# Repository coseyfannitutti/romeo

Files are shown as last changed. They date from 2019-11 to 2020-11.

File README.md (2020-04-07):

# ROMEO
 Staggered 40% QMK and VIA compatible keyboard pcb assembled with only through hole components, including USB Type-C

**[BOM, Build Guide, and Flashing Information](./doc)**

**Kits available at [cftkb.com](https://www.cftkb.com)**

**[Optional High Profile Lasercut Acrylic Case](./case)**

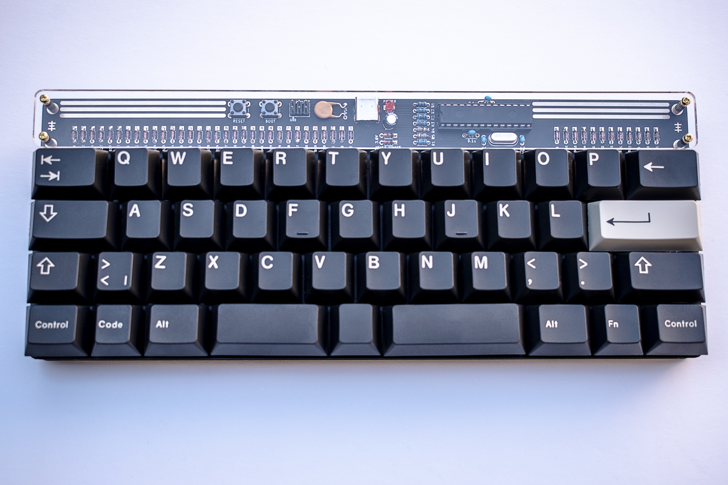
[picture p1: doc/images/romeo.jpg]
romeo

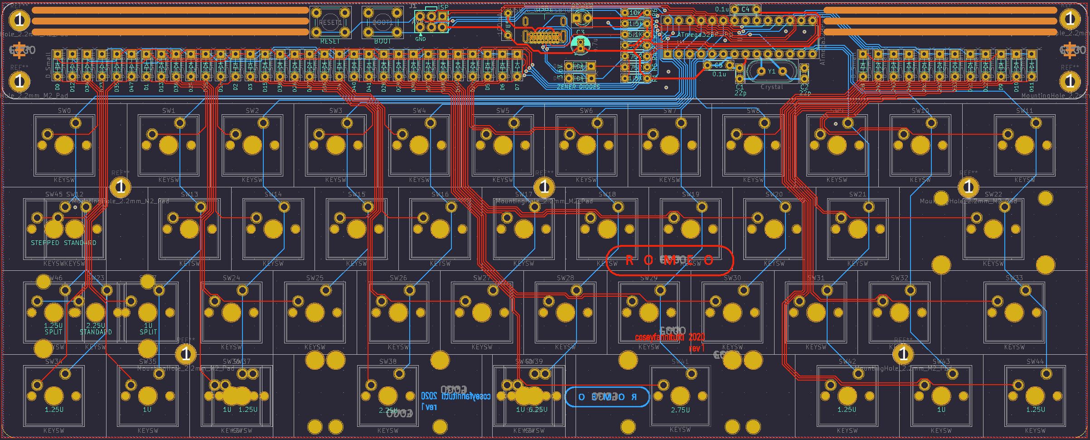
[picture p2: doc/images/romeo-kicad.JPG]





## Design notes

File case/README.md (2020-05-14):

# Lasercut Acrylic Case with POM Plate

***This is case is OPTIONAL and not required. The kit has everything you need for a fully functional keyboard.
This case uses a different plate and is NOT compatible with the plate included in the kit.
If you have already soldered switches, you will need to desolder them and swap the plate.***

***I recommend using [Ponoko](https://www.ponoko.com) to cut the pieces. They have all of the correct/required thicknesses and materials in stock and have the best pricing that I have found for multiple one-off parts. Use clear acrylic for the full range of thickness options and Delrin (POM) for the plate. For proper fit please ensure you use the correct dimensions and material thicknesses noted below. romeo-top-1.dxf must be clear for component window. 3mm pieces will have full range of color options. 4.5mm open layer will have limited color choices but will only be visible from the side.***

***Ponoko's automatic size detection when uploading is not flawless, so be sure to manually enter the dimensions below.***

## Part Dimensions/Thickness (Top to Bottom)
1. romeo-top-1.dxf - 263.7 x 115.2 mm - ***2mm thickness clear acrylic***
2. romeo-top-2.dxf ***x2 needed*** - 263.7 x 115.2 mm - ***3mm thickness acrylic (Matte/frosted or color recomended for winkeyless version to hide plate hole.)***
3. romeo-plate.dxf - 263.7 x 115.2 mm - ***1.5mm thickness DELRIN(POM)*** Can be black or white.
4. romeo-open-layer.dxf - 263.7 x 115.2 mm - ***4.5mm thickness acrylic***
5. romeo-closed-layer.dxf - 263.7 x 115.2 mm - ***3mm thickness acrylic***
6. romeo-bottom.dxf - 263.7 x 115.2 mm - ***3mm thickness acrylic***
7. romeo-foot-1.dxf - 241.1 x 22mm - ***3mm thickness acrylic***
8. romeo-foot-2.dxf - 238.1 x 19mm - ***3mm thickness acrylic***
9. romeo-foot-3.dxf - 235.1 x 16mm - ***3mm thickness acrylic***

## Screws and Standoffs
1. [22x m2x5mm screws](https://www.aliexpress.com/item/32870342767.html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,searchweb201602_7,searchweb201603_53)
2. [8x m2x14mm standoffs](https://www.aliexpress.com/item/32968906213.html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,searchweb201602_7,searchweb201603_53)
3. [3x m2x5mm standoffs](https://www.aliexpress.com/item/32968906213.html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,searchweb201602_7,searchweb201603_53)

romeo


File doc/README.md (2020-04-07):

# ROMEO

**[Build Guide](https://static1.squarespace.com/static/5c533d33348cd92b886e544d/t/5e767acd0ff82c232030b20b/1584822992123/ROMEO+BUILD+GUIDE.pdf)**

**[VIA Configurator Guide](https://static1.squarespace.com/static/5c533d33348cd92b886e544d/t/5e8bd35323fb224b2f3c259d/1586221908208/ROMEO+VIA+GUIDE.pdf)**

**[QMK Toolbox Flashing Guide (Recommended)](https://static1.squarespace.com/static/5c533d33348cd92b886e544d/t/5e73f6b325afdb570c7bbe6a/1584658100264/ROMEO+FLASHING+GUIDE.pdf)**

**[Command Line Flashing Guide (Advanced)](https://static1.squarespace.com/static/5c533d33348cd92b886e544d/t/5e73f6c5d50dac3992a99da3/1584658118097/ROMEO+FLASHING+GUIDE+-+COMMAND+LINE.pdf)**

**[Bootloader](./bootloader)**

**[BOM (Parts List)](https://octopart.com/bom-tool/7JrzAlX8)**

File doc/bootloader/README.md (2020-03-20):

# Bootloader

## If you buy a kit from cftkb.com your microcontroller already has the bootloader flashed and you do not need this.

This project uses USBaspLoader as the usb bootloader on the atmega328p.
- My custom bootloader:   
https://github.com/coseyfannitutti/USBaspLoader/tree/atmega328p
  - Please ensure you are in the atmega328p branch of my fork of the USBaspLoader repository when downloading.
  - Follow the directions in the readme for directions on setting up the build environment for your operating system as well as flash instructions.
  - Makefile.inc sets flashing device as usbtiny, as I use a sparkfun pocket avr programmer. If you need to use another programmer please edit line 41 of Makefile.inc accordingly. Only edit Makefile.inc, and NEVER directly edit the actual Makefile.
  - Commands for flashing once build environment is set up:
  
	```make flash``` (flashes makefile)
  
  	```make fuse``` (sets fuses for microcontroller)
  
## Enter bootloader mode
1. Press and hold ```BOOT``` switch
2. Tap ```RESET``` switch
3. Release ```BOOT``` switch

Alternatively, you can hold ```BOOT``` switch while inserting the USB cable.

If you have successfully entered bootloader mode you should see USBaspLoader in device manager or as a connected device in QMK Toolbox.

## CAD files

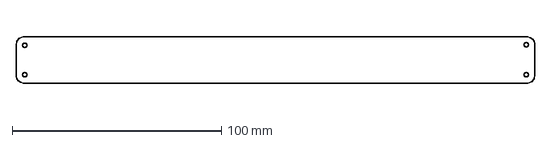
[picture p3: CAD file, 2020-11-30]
acrylic-guard.dxf
247.7 x 22.0 mm

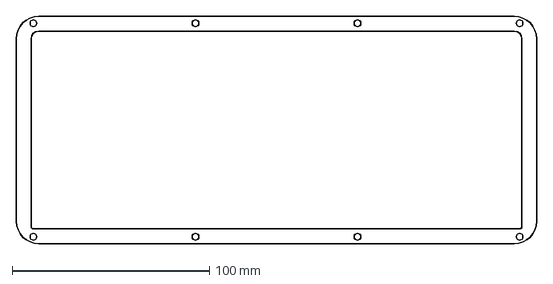
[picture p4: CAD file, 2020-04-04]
case/standard/romeo-top-2.dxf
263.7 x 115.2 mm

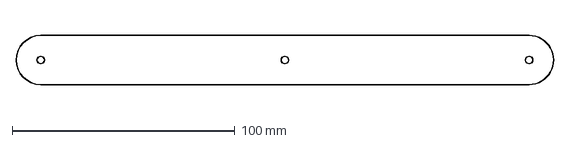
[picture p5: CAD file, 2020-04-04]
case/winkeyless/romeo-foot-1.dxf
241.6 x 22.0 mm

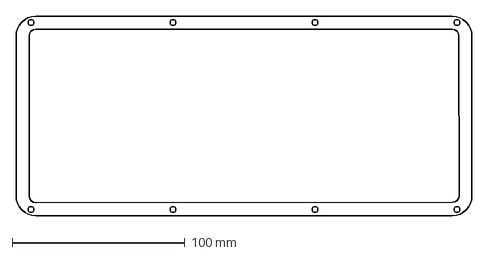
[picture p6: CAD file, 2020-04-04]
case/standard/romeo-closed-layer.dxf
263.7 x 115.2 mm

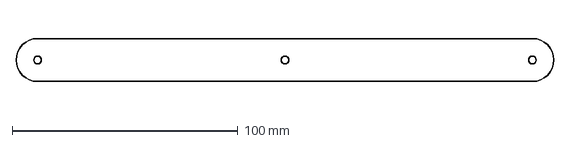
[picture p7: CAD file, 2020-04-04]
case/winkeyless/romeo-foot-2.dxf
238.1 x 19.0 mm

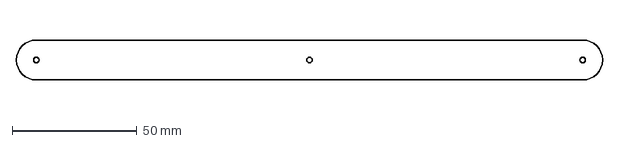
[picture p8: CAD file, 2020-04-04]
case/winkeyless/romeo-foot-3.dxf
235.1 x 16.0 mm

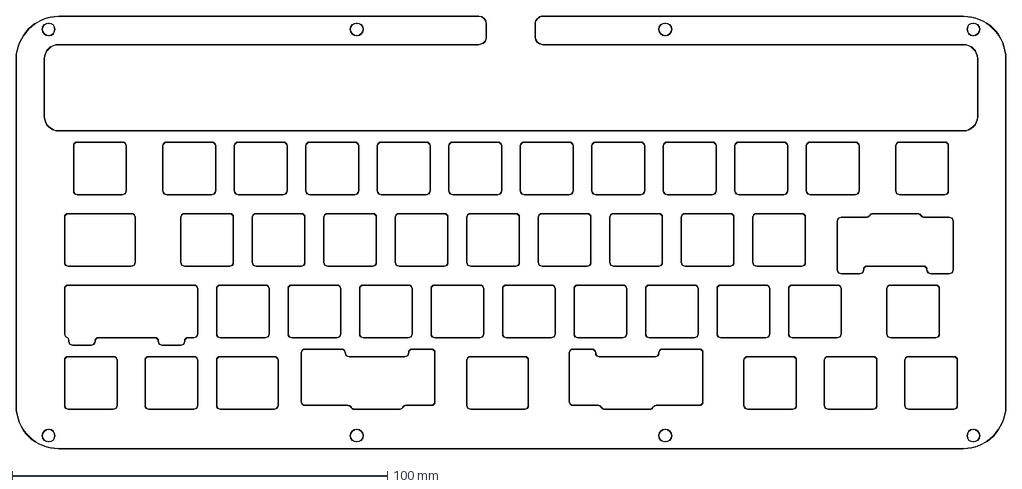
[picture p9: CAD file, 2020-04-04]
case/standard/romeo-plate.dxf
263.7 x 115.2 mm

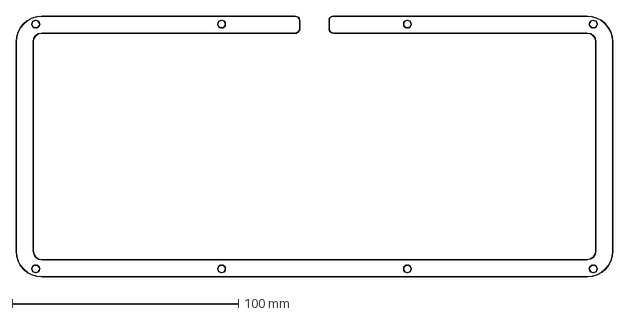
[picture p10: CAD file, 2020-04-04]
case/winkeyless/romeo-open-layer.dxf
263.7 x 115.2 mm

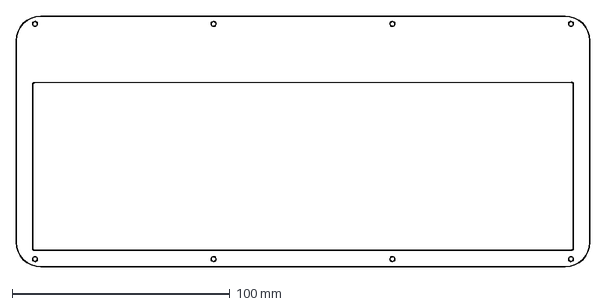
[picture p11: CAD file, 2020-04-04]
case/standard/romeo-top-1.dxf
263.7 x 115.2 mm

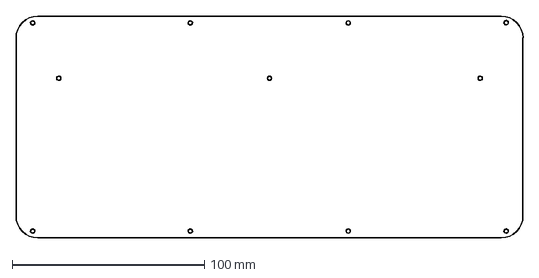
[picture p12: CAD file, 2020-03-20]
case/winkeyless/romeo-bottom.dxf
263.7 x 115.2 mm

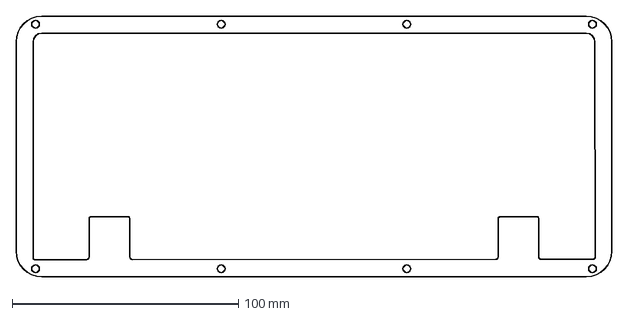
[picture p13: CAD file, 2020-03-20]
case/winkeyless/romeo-top-2-wkl.dxf
263.7 x 115.2 mm

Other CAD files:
case/winkeyless/romeo-top-1-wkl.dxf

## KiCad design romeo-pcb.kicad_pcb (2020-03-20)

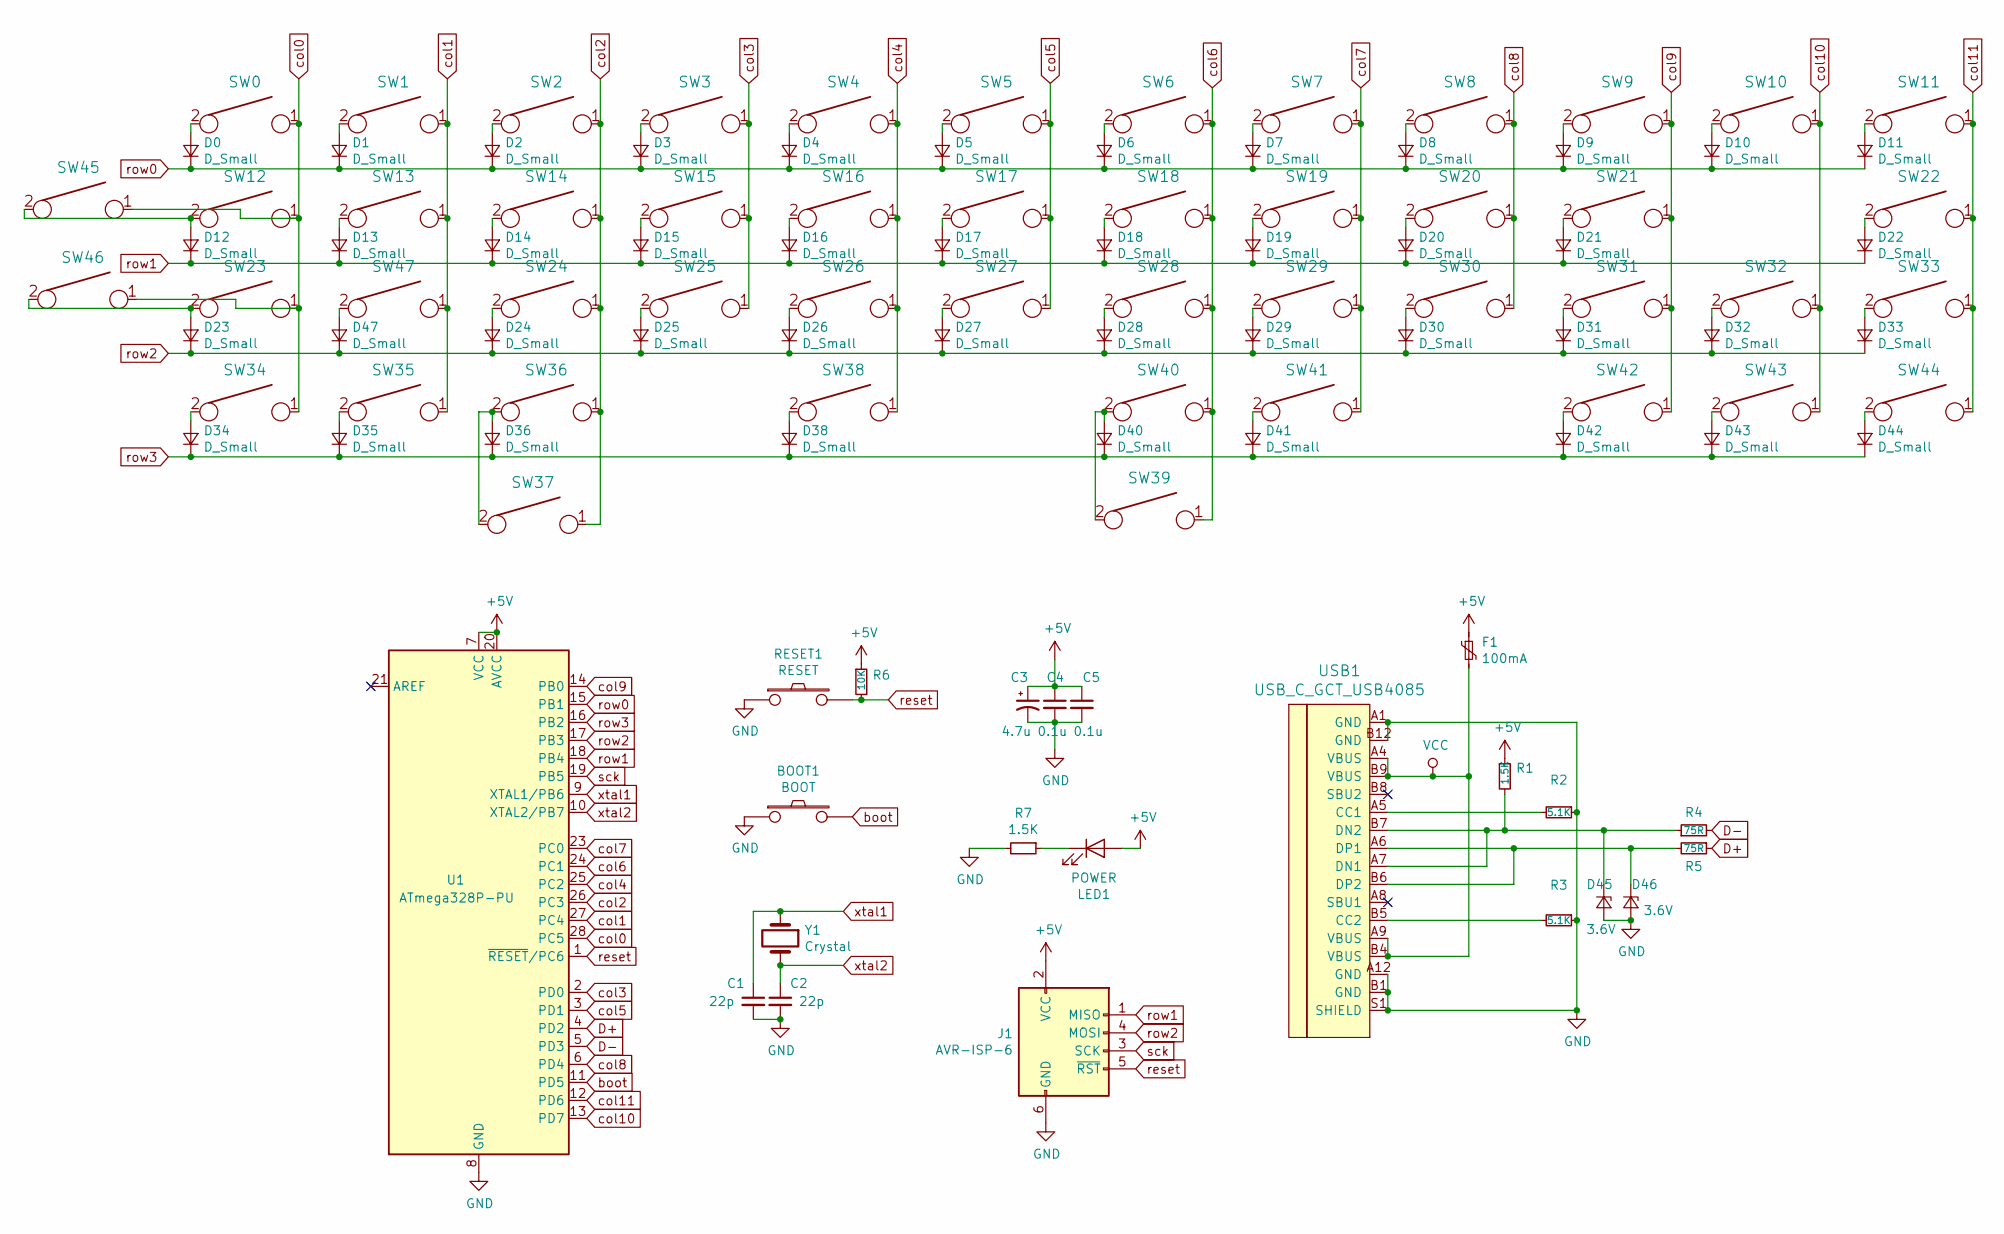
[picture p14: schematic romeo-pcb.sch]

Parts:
BOOT1: BOOT; SW_PUSH_6mm
C1, C2: 22p; C_Disc_D3.0mm_W1.6mm_P2.50mm
C3: 4.7u; CP_Radial_D4.0mm_P1.50mm
C4, C5: 0.1u; C_Disc_D4.3mm_W1.9mm_P5.00mm
D0, D1, D2, D3, D4, D5, D6, D7, D8, D9, D10, D11, D12, D13, D14, D15, D16, D17, D18, D19, D20, D21, D22, D23, D24, D25, D26, D27, D28, D29, D30, D31, D32, D33, D34, D35, D36, D38, D40, D41, D42, D43, D44, D47: D_Small; D_DO-35_SOD27_P5.08mm_Horizontal
D45, D46: 3.6V; D_DO-35_SOD27_P5.08mm_Horizontal
F1: 100mA; polyfuse_5.1mm
J1: AVR-ISP-6; AVR_ICSP_3x2
LED1: POWER; LED_D3.0mm
R1, R7: 1.5K; R_Axial_DIN0204_L3.6mm_D1.6mm_P5.08mm_Horizontal
R2, R3: 5.1K; R_Axial_DIN0204_L3.6mm_D1.6mm_P5.08mm_Horizontal
R4, R5: 75R; R_Axial_DIN0204_L3.6mm_D1.6mm_P5.08mm_Horizontal
R6: 10K; R_Axial_DIN0204_L3.6mm_D1.6mm_P5.08mm_Horizontal
RESET1: RESET; SW_PUSH_6mm
SW0, SW11: KEYSW; SW_Cherry_MX1A_1.50u_PCBNOSCREEN
SW1, SW2, SW3, SW4, SW5, SW6, SW7, SW8, SW9, SW10, SW13, SW14, SW15, SW16, SW17, SW18, SW19, SW20, SW21, SW24, SW25, SW26, SW27, SW28, SW29, SW30, SW31, SW32, SW35, SW36, SW39, SW40, SW43, SW47: KEYSW; SW_Cherry_MX1A_1.00u_PCB-NOSCREEN
SW12, SW33: KEYSW; SW_Cherry_MX1A_1.75u_PCBNOSCREEN
SW22, SW23, SW38: KEYSW; SW_Cherry_MX1A_2.25u_PCBNOSCREEN
SW34, SW37, SW42, SW44, SW45, SW46: KEYSW; SW_Cherry_MX1A_1.25u_PCBNOSCREEN
SW41: KEYSW; SW_Cherry_MX1A_2.75u_PCB_NOSCREEN
U1: ATmega328P-PU; DIP-28_W7.62mm
USB1: USB_C_GCT_USB4085
Y1: Crystal; Crystal_HC49-4H_Vertical

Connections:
+5V: C3.1, C4.1, C5.1, F1.1, J1.2 (VCC), LED1.2 (A), R1.1, R6.1, U1.7 (VCC), U1.20 (AVCC)
D+: R5.1, U1.4 (PD2)
D-: R4.2, U1.5 (PD3)
GND: BOOT1.1, C1.2, C2.2, C3.2, C4.2, C5.2, D45.2 (A), D46.2 (A), J1.6 (GND), R2.1, R3.1, R7.2, RESET1.1, U1.8 (GND), U1.22 (GND), USB1.A1 (GND), USB1.A12 (GND), USB1.B1 (GND), USB1.B12 (GND), USB1.S1 (SHIELD)
unnamed: D0.2 (A), SW0.2
unnamed: D1.2 (A), SW1.2
unnamed: D2.2 (A), SW2.2
unnamed: D3.2 (A), SW3.2
unnamed: D4.2 (A), SW4.2
unnamed: D5.2 (A), SW5.2
unnamed: D6.2 (A), SW6.2
unnamed: D7.2 (A), SW7.2
unnamed: D8.2 (A), SW8.2
unnamed: D9.2 (A), SW9.2
unnamed: D10.2 (A), SW10.2
unnamed: D11.2 (A), SW11.2
unnamed: D12.2 (A), SW12.2, SW45.2
unnamed: D13.2 (A), SW13.2
unnamed: D14.2 (A), SW14.2
unnamed: D15.2 (A), SW15.2
unnamed: D16.2 (A), SW16.2
unnamed: D17.2 (A), SW17.2
unnamed: D18.2 (A), SW18.2
unnamed: D19.2 (A), SW19.2
unnamed: D20.2 (A), SW20.2
unnamed: D21.2 (A), SW21.2
unnamed: D22.2 (A), SW22.2
unnamed: D23.2 (A), SW23.2, SW46.2
unnamed: D24.2 (A), SW24.2
unnamed: D25.2 (A), SW25.2
unnamed: D26.2 (A), SW26.2
unnamed: D27.2 (A), SW27.2
unnamed: D28.2 (A), SW28.2
unnamed: D29.2 (A), SW29.2
unnamed: D30.2 (A), SW30.2
unnamed: D31.2 (A), SW31.2
unnamed: D32.2 (A), SW32.2
unnamed: D33.2 (A), SW33.2
unnamed: D34.2 (A), SW34.2
unnamed: D35.2 (A), SW35.2
unnamed: D36.2 (A), SW36.2, SW37.2
unnamed: D38.2 (A), SW38.2
unnamed: D40.2 (A), SW39.2, SW40.2
unnamed: D41.2 (A), SW41.2
unnamed: D42.2 (A), SW42.2
unnamed: D43.2 (A), SW43.2
unnamed: D44.2 (A), SW44.2
unnamed: D45.1 (K), R1.2, R4.1, USB1.A7 (DN1), USB1.B7 (DN2)
unnamed: D46.1 (K), R5.2, USB1.A6 (DP1), USB1.B6 (DP2)
unnamed: D47.2 (A), SW47.2
unnamed: LED1.1 (K), R7.1
unnamed: R2.2, USB1.A5 (CC1)
unnamed: R3.2, USB1.B5 (CC2)
VCC: F1.2, USB1.A4 (VBUS), USB1.A9 (VBUS), USB1.B4 (VBUS), USB1.B9 (VBUS)
boot: BOOT1.2, U1.11 (PD5)
col0: SW0.1, SW12.1, SW23.1, SW34.1, SW45.1, SW46.1, U1.28 (PC5)
col1: SW1.1, SW13.1, SW35.1, SW47.1, U1.27 (PC4)
col2: SW2.1, SW14.1, SW24.1, SW36.1, SW37.1, U1.26 (PC3)
col3: SW3.1, SW15.1, SW25.1, U1.2 (PD0)
col4: SW4.1, SW16.1, SW26.1, SW38.1, U1.25 (PC2)
col5: SW5.1, SW17.1, SW27.1, U1.3 (PD1)
col6: SW6.1, SW18.1, SW28.1, SW39.1, SW40.1, U1.24 (PC1)
col7: SW7.1, SW19.1, SW29.1, SW41.1, U1.23 (PC0)
col8: SW8.1, SW20.1, SW30.1, U1.6 (PD4)
col9: SW9.1, SW21.1, SW31.1, SW42.1, U1.14 (PB0)
col10: SW10.1, SW32.1, SW43.1, U1.13 (PD7)
col11: SW11.1, SW22.1, SW33.1, SW44.1, U1.12 (PD6)
reset: J1.5 (~RST), R6.2, RESET1.2, U1.1 (~RESET~/PC6)
row0: D0.1 (K), D1.1 (K), D2.1 (K), D3.1 (K), D4.1 (K), D5.1 (K), D6.1 (K), D7.1 (K), D8.1 (K), D9.1 (K), D10.1 (K), D11.1 (K), U1.15 (PB1)
row1: D12.1 (K), D13.1 (K), D14.1 (K), D15.1 (K), D16.1 (K), D17.1 (K), D18.1 (K), D19.1 (K), D20.1 (K), D21.1 (K), D22.1 (K), J1.1 (MISO), U1.18 (PB4)
row2: D23.1 (K), D24.1 (K), D25.1 (K), D26.1 (K), D27.1 (K), D28.1 (K), D29.1 (K), D30.1 (K), D31.1 (K), D32.1 (K), D33.1 (K), D47.1 (K), J1.4 (MOSI), U1.17 (PB3)
row3: D34.1 (K), D35.1 (K), D36.1 (K), D38.1 (K), D40.1 (K), D41.1 (K), D42.1 (K), D43.1 (K), D44.1 (K), U1.16 (PB2)
sck: J1.3 (SCK), U1.19 (PB5)
xtal1: C1.1, U1.9 (XTAL1/PB6), Y1.1
xtal2: C2.1, U1.10 (XTAL2/PB7), Y1.2

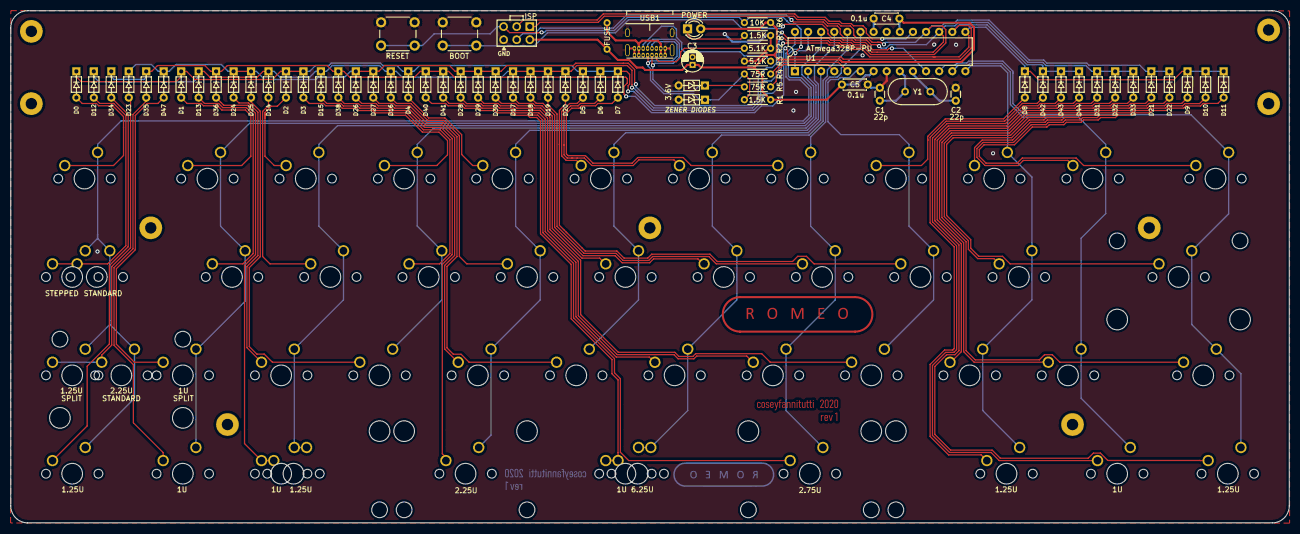
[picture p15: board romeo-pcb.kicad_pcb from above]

Board: 2 copper layers, 247.6 x 99.2 mm, 115 parts (0 on the bottom side), 75 nets.

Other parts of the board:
ST39: 6.25U; MX-6.25U-Stabilizer

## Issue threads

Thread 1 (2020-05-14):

Ponoko Acrylic Case Parts and Asssembly

goranzarkovic, 2020-05-14:
Maybe I did something wrong but I have looked over the Readme and glanced at the renders for the custom acrylic case and I am not sure if maybe the parts needed count is slightly off.

It says 14x m2x5mm screws but around the border itself i think it needs 8 from the top and bottom (16) and then 3 more from the top and bottom of the feet (6), so 22 total.

Also, how does the PCB sit in the case?
Is it sort of floating because the 3 holes on the bottom plate do not match up with holes on the PCB, and the pcb sort of currently rubs against the top screws, which i assume is resolved by soldering the plate mounted switches.

coseyfannitutti, 2020-05-14:
Yes, the readme has been changed to reflect that difference in screw count.

The bottom plate from the kit and the screw holes on the pcb should not be used with the acrylic case. The PCB is held up by the plate included in this repository once switches are soldered.

goranzarkovic, 2020-05-14:
Excellent thank you!

Closed 2020-05-14.

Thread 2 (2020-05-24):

Acrylyc-Guard size?

lednax, 2020-05-24:
I've been looking through the repo but I can't find a reference to the size. Ponoko is not processing the size correctly.

Can you include it in the README or somewhere else?

Thank you!

lednax, 2020-06-02:
BUMP

IOPNR, 2020-07-24:
>
>
> BUMP

Were you ever able to find the dimensions?

dayofdoom, 2020-11-28:
I laser cut the acrylic guard in the repo today and it was the wrong size. If I had to guess, I think it's the mysterium's guard.

coseyfannitutti, 2020-11-30:
@dayofdoom The way it was previously saved may have caused some potential scaling issues depending on what program it was opened with. I have changed the file to prevent that. Should be good now.

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
@lednax Sorry I didn't see this until now.

Closed 2020-11-30.

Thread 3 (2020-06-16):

Acrylic guard bends easily, causing it to get poked by the header pins

kusamakura, 2020-06-16:
I appreciate the simplicity of four mounting points for the acrylic guard. But I have found that in normal use, such as picking up the keyboard, or holding the keyboard to support it when plugging a USB cable, the acrylic guard can hit the header pins, leaving permanent damage marks. I suppose this isn't a problem with the Discipline or the Mysterium because there are additional mounting points in the middle to support the guard; the Romeo, however, doesn't have this. I realize this is a very minor issue, but decided to let you know nonetheless, just in case. ;)

Anyway, great job on this board. It's a great first foray into the world of 40s.

mabinin427, 2020-08-13:
Where did you find the dimensions to the acrylic guard?

kusamakura, 2020-08-13:
> Where did you find the dimensions to the acrylic guard?

@mabinin427 I have the actual board.

But a quick look at the repo yields this: https://github.com/coseyfannitutti/romeo/blob/master/acrylic-guard.dxf

mabinin427, 2020-08-13:
Oh okay. I guess I'll have to open that file then on my kicad. Since you have a romeo do you by any chance know why this does not seem to have a Gerber file for the plate other than what's provided for custom acrylic case?

kusamakura, 2020-08-13:
> Since you have a romeo do you by any chance know why this does not seem to have a Gerber file for the plate other than what's provided for custom acrylic case?

Uh, I don't see how those are connected, but @coseyfannitutti simply forgot to add it?

Closed 2020-11-30.

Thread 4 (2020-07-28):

Plate for Romeo

IOPNR, 2020-07-28:
I'm having difficulty finding files for the Romeo plate. I saw that they were mentioned in the build guide but am not seeing it in the master files. Are the plate files available?

Edit: @coseyfannitutti Just wanted to follow up with this question in case you missed it. TIA Bryan!

mabinin427, 2020-08-13:
I too am wondering why there isn't a Gerber file for the plate. Have you been able to find it?

ymotongpoo, 2020-11-30:
ditto. It's great if you could add it onto the repository.

coseyfannitutti, 2020-11-30:
I am working on a slight refresh for the romeo design that will include plate design. The repository will be updated with those files when it's done.

Closed 2020-11-30.

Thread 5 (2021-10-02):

Question

twinkletoes1724, 2021-10-02:
Hey there! i've planning to build this pcb, but i have issue with the guideline build that you've shared, i don't know how much voltages that all those capacitor you were using? pls help thank you

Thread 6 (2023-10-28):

Broken links to pdf

amhndu, 2023-10-28:
Hi, all links to documentation that leads to some squarespace link seems to be broken

vuksavic, 2024-01-30:
seconding this, i've managed to assemble the pcb but have no idea how to flash the firmware, nor how to make the keeb recognizable by my devices

kofoedanders, 2024-11-26:
@vuksavic What about the build guide, did you manage to get that as well?

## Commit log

2019-11-02 Update romeo-pcb.kicad_pcb-bak
2020-02-06 Update romeo-pcb.sch-bak
2020-03-20 Update PCB and add case files
    [romeo-bottom.dxf, romeo-closed-layer.dxf, romeo-foot-1.dxf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]
2020-03-20 Consolidate gerber files
    [Component1.step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]
2020-04-04 fix scaling
    [romeo-closed-layer.dxf, romeo-foot-1.dxf, romeo-foot-2.dxf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]
2020-11-30 Update acrylic-guard.dxf
    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
    [acrylic-guard.dxf]
